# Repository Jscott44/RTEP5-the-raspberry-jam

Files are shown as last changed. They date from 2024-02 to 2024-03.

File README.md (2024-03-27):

<!-- display the social media buttons in your README -->

<!-- To Link your profile to the media buttons -->

# **The Raspberry Jam**

The realtime Raspberry PI powered digital guitar effects pedal.

<div style="float:left;margin:0 1px 1px 0" markdown="2">

logoPicBlkStrip

</div>

# **Usage**

Ensure the Raspberry Pi is updated:

```bash
# Update package lists
sudo apt update

# Upgrade installed packages
sudo apt upgrade

# Remove unused packages
sudo apt autoremove

# Clean up package cache
sudo apt clean
```
Install Git 
```bash
# Install Git
sudo apt-get install git -y

# Verify Git installation
git --version
```
Install ALSA resources
```bash
# Install ALSA utilities and libraries
sudo apt-get install alsa-utils libasound2-dev -y

# Verify ALSA installation
aplay --version
```
Install CMake in order to build the project
```bash
# Install CMake
sudo apt-get install cmake -y

# Verify CMake installation
cmake --version
```
Clone the repository
```bash
# Clone the repository from GitHub
git clone https://github.com/Jscott44/RTEP5-the-raspberry-jam.git

# Change directory to the cloned repository
cd RTEP5-the-raspberry-jam

# List files in the repository
ls
```
For use with a generic sound card a device tree overlay needs to be created.

To make sound card master and Raspberry Pi on I2S bus (credit: https://github.com/AkiyukiOkayasu/RaspberryPi_I2S_Slave):
```bash
# Change to device tree directory
cd deviceTree

# Compile on Raspberry Pi  
dtc -@ -H epapr -O dtb -o genericstereoaudiocodec.dtbo -Wno-unit_address_vs_reg genericstereoaudiocodec.dts

# Copy i2smaster.dtbo to /boot/overlays  
sudo cp genericstereoaudiocodec.dtbo /boot/overlays

# Return to repository directory
cd ..
```

Edit /boot/config.txt   
```/boot/config.txt    # Uncomment some or all of these to enable the optional hardware interface
#dtparam=i2c_arm=on
dtparam=i2s=on
#dtparam=spi=on
dtoverlay=genericstereoaudiocodec
```
To make sound card slave and Raspberry Pi master on I2S bus (credit: https://github.com/AkiyukiOkayasu/RaspberryPi_I2S_Master):

```bash
# Compile on Raspberry Pi
# Change to device tree directory
cd deviceTree

dtc -@ -H epapr -O dtb -o i2smaster.dtbo -Wno-unit_address_vs_reg i2smaster.dts

# Copy i2smaster.dtbo to /boot/overlays  
sudo cp i2smaster.dtbo /boot/overlays

# Return to repository directory
cd ..
```

Edit /boot/config.txt  
```/boot/config.txt
# Uncomment some or all of these to enable the optional hardware interface
#dtparam=i2c_arm=on
dtparam=i2s=on
#dtparam=spi=on
dtoverlay=i2smaster
```

Bulding the project with CMake
```bash 
# Create a build directory (optional)
mkdir -p build
cd build

# Configure the build using CMake
cmake ..

# Build the project
make
```
# **Key Features**
- Realtime audio loop
- Cutsomisable effects
- User profiles
- Low cost
- Simple effect creation
- Specialised audio electronics design
RJ_Schematic_v1 0

# **Social Media Links**
[instagram][2]
[github][5]

[2]: https://www.instagram.com/the_raspberry_jam/ 
[5]: https://github.com/Jscott44/RTEP5-the-raspberry-jam

# **Authors and Roles**
- **Jed Scott**
  - Project Manager, Software (audio driver), Hardware Lead, Social Media Lead
- **Dario Petinella**
  - Software Lead (audio driver, effects manager), Integration Lead, Hardware (audio)
- **Alan Hamilton**
  - Software (GUI Lead and effects integration), Mechanical Support
- **Elad Perets**
  - Software (effects), Hardware (pedal)
- **Matthew Stewart**
  - Software (GUI)

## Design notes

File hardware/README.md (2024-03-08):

# **Hardware**
The Raspberry Jam includes a specialised audio sound card for the capture and playback of high fidelity audio. The impact of the hardware is designed to be as inaudible as possible and all of the effects are achieved digitally in software. The hardware design is modular in nature allowing the cutsomisation to suit different applications.

# **Features**
- Highly integrated stereo audio CODEC
- Sample rates: 44.1kHz, 48kHz, 96kHz or 192kHz
- Hardware or Software control
- On-board oscillator
- 1x mono audio input (guitar)
- 2x stereo outputs (speakers)
- 1x stereo output (headphones with volume control)

# **Audio Inputs and Outputs**
The current version of the sound card supports one single ended mono instrument input up to 2Vrms. 
inputConn

The output support two single ended connectors to create a stereo speaker output with a maximum level of 1.8Vrms before amplification. 
outConn

The output also support a headphone driver with analogue volume to control to adjust to different load impedance headphones.
- Default gain range 18dB.
- To alter gain range adjust R43, R44, R45 and R46.
- Adjust output power by altering R41 and R42.
HPConn

# **CODEC**

cdc

<h2>CS4271 Sample Rate Truth Table</h2>

<table>
  <tr>
    <th>Resistor R49</th>
    <th>Resistor R50</th>
    <th>Resistor R10</th>
    <th>Resistor R11</th>
    <th>M1</th>
    <th>M0</th>
    <th>Sample Rate (kHz)</th>
  </tr>
  <tr>
    <td>Not Populated</td>
    <td>Not Populated</td>
    <td>Populated</td>
    <td>Populated</td>
    <td>0</td>
    <td>0</td>
    <td>44.1</td>
  </tr>
  <tr>
    <td>Not Populated</td>
    <td>Populated</td>
    <td>Populated</td>
    <td>Not Populated</td>
    <td>0</td>
    <td>1</td>
    <td>48</td>
  </tr>
  <tr>
    <td>Populated</td>
    <td>Not Populated</td>
    <td>Not Populated</td>
    <td>Populated</td>
    <td>1</td>
    <td>0</td>
    <td>96</td>
  </tr>
  <tr>
    <td>Populated</td>
    <td>Populated</td>
    <td>Not Populated</td>
    <td>Not Populated</td>
    <td>1</td>
    <td>1</td>
    <td>192</td>
  </tr>
</table>

</body>
</html>
</html>

<h2>CS4271 Audio Mode Truth Table</h2>

<table>
  <tr>
    <th>R9 </th>
    <th>R32 </th>
    <th>ADO </th>
    <th>Audio Mode</th>
  </tr>
  <tr>
    <td>Populated</td>
    <td>Not Populated</td>
    <td>1</td>
    <td>I2S</td>
  </tr>
  <tr>
    <td>Not Populated</td>
    <td>Populated</td>
    <td>0</td>
    <td>Left Justified</td>
  </tr>

  </tr>
</table>

</body>
</html>

# **Digital Audio Format**

By default the digital audio interface will operate using the I2S protocol
- MSB first (big endian)
- Signed 24-bits per channel
- 2 channels
- Interleaved channels

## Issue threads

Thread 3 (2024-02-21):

Driver for capture from generic PCM device

Jscott44, 2024-02-21:
Basic functionality to recognise and then read from PCM device

iamdario, 2024-02-22:
Created _audio_driver_dev_ branch for development to begin.

Jscott44, 2024-02-26:
Created branch for specific capture development

Jscott44, 2024-03-04:
Created basic framework for a generic device, waiting for finalised development of hardware platform in order to properly test interface with RPI.

iamdario, 2024-03-14:
Has been implemented in the branch 'capture-from-generic-pcm-device'. Need to now merge effects manager to begin testing.

iamdario, 2024-03-23:
Has been achieved and merged back into 'audio_driver_dev' branch in pull request #58 .

Closed 2024-03-23.

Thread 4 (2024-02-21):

Driver for playback to generic PCM device

Jscott44, 2024-02-21:
Functionality to write to a PCM device

iamdario, 2024-02-22:
Created _audio_driver_dev_ branch for development to begin.

Jscott44, 2024-03-04:
Waiting for hardware platform to be finished.

Jscott44, 2024-03-05:
Added parent class that will define basic functions and configure settings. Capture and playback will be children of this class, settings are shared as much as possible and functions will be implemented differently where necessary.

iamdario, 2024-03-14:
Has been implemented in the branch 'capture-from-generic-pcm-device'. Need to now merge effects manager to begin testing.

iamdario, 2024-03-23:
Has been achieved and merged back into 'audio_driver_dev' branch in pull request #58 .

Closed 2024-03-23.

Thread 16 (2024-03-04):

QTabWidget Current Index -> Effects Manager pointer relation

AlanHam42, 2024-03-04:
The user can only affect the current index of tabs.
The EM returns a pointer for each new tab.
Each pointer needs to be stored in the same order as the tabs, and destroyed with the tabs.
The current index can then refer to the correct pointer, which will return values to the EM.

theOriginalMC, 2024-03-29:
GUI now receives a pointer and sends variables to the Effects Manager

Closed 2024-03-29.

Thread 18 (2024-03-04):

Create Basic Effects Manager

iamdario, 2024-03-04:
This class will be responsible for taking the data from Alsa (that has been converted using AlsaBufferConverter into a usable form) and applying effects to the data. Some of the groundwork must also be created to allow the GUI to create/destroy different effects.

iamdario, 2024-03-05:
Basic functionality has been added. Can now add effects, remove effects and apply effects to data.

iamdario, 2024-03-05:
Next: Add way to allow GUI to alter parameters effect classes by calling method

iamdario, 2024-03-14:
As basic functionality has been achieved, it will now be merged with the pcm driver classes to begin testing. Any further alterations required will be added as their own issues.

Closed 2024-03-14.

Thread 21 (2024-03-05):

Add setup and usage instructions for Raspberry Jam in README

Jscott44, 2024-03-05:
Once hardware is finalised this can be done.

Jscott44, 2024-03-05:
This also applies to generally fleshing out the documentation for the project.

Jscott44, 2024-03-12:
Added basic update commands for rpi and git install instructions

Jscott44, 2024-03-22:
This now includes all needed steps to set up RPI for use with program including creating a device tree overlay if required.

Jscott44, 2024-03-22:
Done

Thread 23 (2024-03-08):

Convert #20 Wrapper Class to use Proper Callbacks

iamdario, 2024-03-08:
Wrapper class should not be used. Create a branch which experiments with having all the classes reference each other to allow for thread-safe callbacks.

iamdario, 2024-03-08:
Branched from issue #20 to experiment with using callbacks instead of wrapper

iamdario, 2024-03-11:
Has been merged into #18 in pull request #24 and #25.

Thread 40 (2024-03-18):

Alter AlsaBufferConverter and EffectsManager to Avoid Buffer Reallocation

iamdario, 2024-03-18:
Currently, whenever we receive a sample from Alsa, two new ChannelSample objects are created. These are allocating memory which is inefficient. What if, instead, we have these object allocate memory in their constructor and remove them from the loop. The buffers are then reallocated every time data is received via the callback.

iamdario, 2024-03-19:
ChannelSamples has been changed to use fixed arrays allocated on the heap rather than vectors. This will allow the same buffers to be reused instead of constantly deleting and creating ChannelSample objects on the heap which would each be responsible for their own vectors. Now, two ChannelSample objects are created on the heap in the constructor of EffectsManager. These objects are constnatly reused until the EffectsManager object is destroyed.

Closed 2024-03-19.

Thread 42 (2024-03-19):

Pthread_mutex_unlock error when running on RPI

Jscott44, 2024-03-19:
Program terminates when run on RPI stating an error with the unlocking a mutex, this does not occur on PC running Linux. Will experiment with compatibility of capture hardware.

Jscott44, 2024-03-19:
Might be caused by sample rate mismatch - will verify.

Closed 2024-03-21.

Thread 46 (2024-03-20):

PcmCapture Unable to Drain

iamdario, 2024-03-20:
It was noticed that the drain handle call for PcmCapture is unable to execute, with the call blocking the program from continuing to function. This only occurs if data has been read. If drain handle is called without ever reading anything, the drain is able to successfully execute.

iamdario, 2024-03-21:
We have noticed that increasing the number of frames per buffer has resolved this issue. We are now using 9600 instead of 128 as we were using before.

iamdario, 2024-03-21:
Issue has been resolved. See Issue #54

Closed 2024-03-21.

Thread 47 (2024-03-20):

Adjust Device Name

iamdario, 2024-03-20:
We have learned that we will likely need to be able to change the device name of the PCM handle. We will need to adjust the code accordingly.

iamdario, 2024-03-21:
Has been resolved. Users can now customise device names from main.cpp. Merged done in #48.

Closed 2024-03-21.

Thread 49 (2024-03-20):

Create Folder Containing Sample Code to Test Hardware

iamdario, 2024-03-20:
Currently, we are struggling to see whether issues arising are from hardware or software. For this reason, we will make a new folder which just has some sample scripts allowing hardware to be tested without the need of running our program. This will allow us to narrow down issues more quickly.

iamdario, 2024-03-21:
Resolved in Pull Request #55 . See Issue #54 .

Closed 2024-03-21.

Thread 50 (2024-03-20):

Adjust Values in Code to use New ADC

iamdario, 2024-03-20:
From experimenting using test programs, we have found that our new ADC has different parameters than what we were expecting. Therefore we will need to adjust these parameters within the code. We have noticed the following:

- The ADC needs 96000Hz sampling rate
- The ADC need uses INT16s instead of INT24s. When adjusting this, we will want to ensure we can easily swap between 16 bit and 24 bit to be compatible with as much audio
- Potentially increase the number of frames as we have noticed that this improved performance (reduced the number of times the ALSA read/write commands failed)

iamdario, 2024-03-20:
Adjusted to allow code to use both int16s and int24. Need to figure out a way to more easily swap between the two. However, the code also needs to be able to handle little endian int16s which it is currently unable to do. Currently considering using an enum and switch statement.

iamdario, 2024-03-21:
The issue has now been solved and we can run the program with the new ADC we have. To do this, we have:
- Allowed the bytes per sample to be swapped between 2 and 3. If it is 2, AlsaBufferConverter will recognise that the ADC will get INT16s and the same will happen when it is 3, with the program recognising that it is using INT24s.
- Program now uses a sample rate of 96kHz and a buffer size of 128. This is a rather large buffer and will potentially result in a noticeable delay. Further investigation is required.
- Program can now swap between reading/writing data as little endian and big endian. This must be adjusted in the header file of AlsaBufferConverter.

These changes have also highlighted another issue. We are realising that, to make this program as flexible as possible, we want to be able to change these values from multiple locations at once to allow users to be able to change these values easily. This will be further investigated in a separate issue.

iamdario, 2024-03-21:
Issue #51 has addressed the previous comment by allowing users to adjust various parameters within main.cpp. Please refer to that issue for further information.

iamdario, 2024-03-21:
Issues is resolved. Merged back into #38.

Closed 2024-03-21.

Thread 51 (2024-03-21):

Allow User to Easily Adjust Values within main.cpp

iamdario, 2024-03-21:
In Issue #50, we have noticed that we will likely have to change values within the code. Right now, it is a painful process as values must be the same within multiple files. I want to change this to allow the user to declare all of these values in the main.cpp file and the constructors of all the classes will take these values as arguments and adjust their code accordingly. The values we want to be able to adjust are:
- Sample Type (INT16 or INT24)
- Sample frequency (96kHz or 44.1kHz)
- Endianness (Little or Big)
- Frames per buffer

iamdario, 2024-03-21:
Has now been resolved. User can now adjust the sample rate, frames per buffer and data format in main.cpp. The program can then figure out what it needs to do from there.

Closed 2024-03-21.

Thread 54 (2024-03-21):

Merge Fixed ALSA Issues

iamdario, 2024-03-21:
From developing the program to use the new ADC discussed in Issue #50 and #51, we have resolved various issues in the process. These include:
- Issue #49 (we no longer need these test files as they were there to figure out the desired digital format for the ADC we were using)
- Issue #46 (it can drain now that we have increased the frames per buffer received.
- Issue #42 (this only occurred once. Upon rebooting the RPI, it disappeared)

These, however, still have branches associated with this. We must clean these branches up.

iamdario, 2024-03-21:
Realised I did not have make this branch. Instead, I can just close all of these open branches that have been resolved separately.

iamdario, 2024-03-21:
Deleting this branch now.

Closed 2024-03-21.

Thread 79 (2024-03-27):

Fix reverb segmentation fault bug

e-perets, 2024-03-27:
Fir filter is causing the program to not run in real time and causing a segmentation fault.

Closed 2024-03-27.

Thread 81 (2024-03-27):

Fix reverb delay line in attempts to make it run in real time

e-perets, 2024-03-27:
The FIR filter method causes segmentation faults and does not run in real time. Attempt implement a ring buffer without the fir library.

Jscott44, 2024-03-28:
tested on rpi, works well

Closed 2024-03-28.

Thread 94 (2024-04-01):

Button for enabling/disabling effect proccessing

iamdario, 2024-04-01:
A button will be required to enable/disable the effects from processing the incoming buffers. This button will interact with the rest of the code using a callback from a class responsible for waiting for an interrupt from a GPIO pin.

Jscott44, 2024-04-04:
Moving to a hybrid system that can use a hardware button or a purely digital button.

AlanHam42, 2024-04-12:
Button has been implemented in GUI.

Closed 2024-04-12.

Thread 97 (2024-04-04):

PiGPIO Conflicts with PCM devices

Jscott44, 2024-04-04:
By default PiGPIO uses the PCM clock (and thus the pins) to establish timing. Most audio devices use the PCM pins also. One can configure PiGPIO to use the PWM clock instead, however it appears the internal sound card on the RPI also uses the PWM clock. Thus, PiGPIO can only be used with using a full duplex sound card on PCM pins and configuring PiGPIO to use the PWM clock.

iamdario, 2024-04-05:
After further testing, we have discovered that the physical button component of The Raspberry Jam would likely not work even with a full duplex sound card. This is because, in order for the button to work, the library being used to read the GPIO pins (PiGPIO) would require SU privileges. However, it has been found that ALSA is unable to function when given SU privileges. This hypothesis was confirmed by the following forum: [Link](https://www.linuxquestions.org/questions/showthread.php?p=6417492#post6417492).

Until a work around is found, this project will move towards implementing a digital button using the GUI.

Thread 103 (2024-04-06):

GUI Only Button

AlanHam42, 2024-04-06:
Ditching the hardware button for now due to issues with Sudo, moving to a digital only button.

Closed 2024-04-12.

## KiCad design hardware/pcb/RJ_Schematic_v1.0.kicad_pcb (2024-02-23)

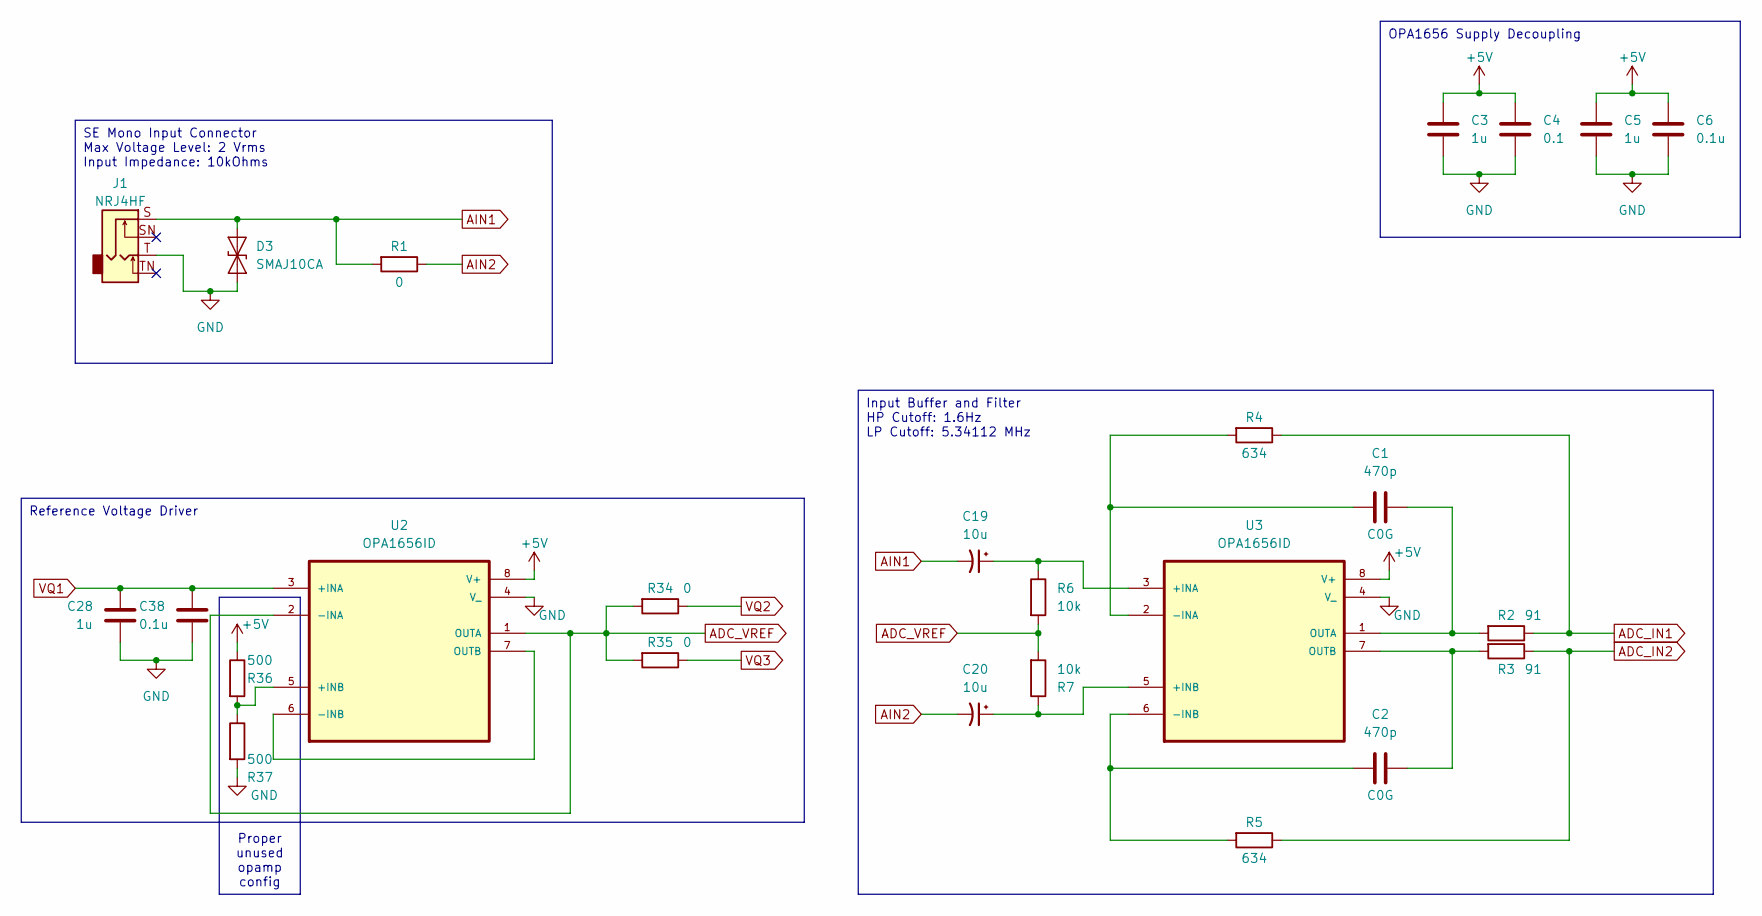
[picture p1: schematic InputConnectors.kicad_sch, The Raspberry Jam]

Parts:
C1, C2: 470p; C_0805_2012Metric_Pad1.18x1.45mm_HandSolder
C3, C5, C28: 1u; C_0805_2012Metric_Pad1.18x1.45mm_HandSolder
C4: 0.1; C_0805_2012Metric_Pad1.18x1.45mm_HandSolder
C6, C38: 0.1u; C_0805_2012Metric_Pad1.18x1.45mm_HandSolder
C19, C20: 10u; CP_Elec_4x5.4
D3: SMAJ10CA; D_SMA
J1: NRJ4HF; Jack_6.35mm_Neutrik_NRJ4HF_Horizontal
R1, R34, R35: 0; R_0805_2012Metric_Pad1.20x1.40mm_HandSolder
R2, R3: 91; R_0805_2012Metric_Pad1.20x1.40mm_HandSolder
R4, R5: 634; R_0805_2012Metric_Pad1.20x1.40mm_HandSolder
R6, R7: 10k; R_0805_2012Metric_Pad1.20x1.40mm_HandSolder
R36, R37: 500; R_0805_2012Metric_Pad1.20x1.40mm_HandSolder
U2, U3: OPA1656ID; SOIC127P599X175-8N

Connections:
+5V: C3.2, C4.2, C5.2, C6.2, R36.1, U2.8 (V+), U3.8 (V+); also elsewhere on the board
ADC_IN1: R2.1, R4.1; also elsewhere on the board
ADC_IN2: R3.1, R5.1; also elsewhere on the board
ADC_VREF: R6.2, R7.2, R34.2, R35.2, U2.1 (OUTA), U2.2 (-INA)
AIN1: C19.2, D3.2 (A2), J1.S, R1.2
AIN2: C20.2, R1.1
GND: C3.1, C4.1, C5.1, C6.1, C28.1, C38.1, D3.1 (A1), J1.T, R37.2, U2.4 (V_), U3.4 (V_); also elsewhere on the board
unnamed: R36.2, R37.1, U2.5 (+INB)
unnamed: U2.6 (-INB), U2.7 (OUTB)
unnamed: C19.1, R6.1, U3.3 (+INA)
unnamed: C20.1, R7.1, U3.5 (+INB)
unnamed: C1.2, R4.2, U3.2 (-INA)
unnamed: C2.2, R5.2, U3.6 (-INB)
unnamed: C1.1, R2.2, U3.1 (OUTA)
unnamed: C2.1, R3.2, U3.7 (OUTB)
VQ1: C28.2, C38.2, U2.3 (+INA); also elsewhere on the board
VQ2: R34.1; also elsewhere on the board
VQ3: R35.1; also elsewhere on the board

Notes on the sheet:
Proper unused opamp config
Input Buffer and Filter HP Cutoff: 1.6Hz LP Cutoff: 5.34112 MHz
OPA1656 Supply Decoupling
Reference Voltage Driver
SE Mono Input Connector Max Voltage Level: 2 Vrms Input Impedance: 10kOhms

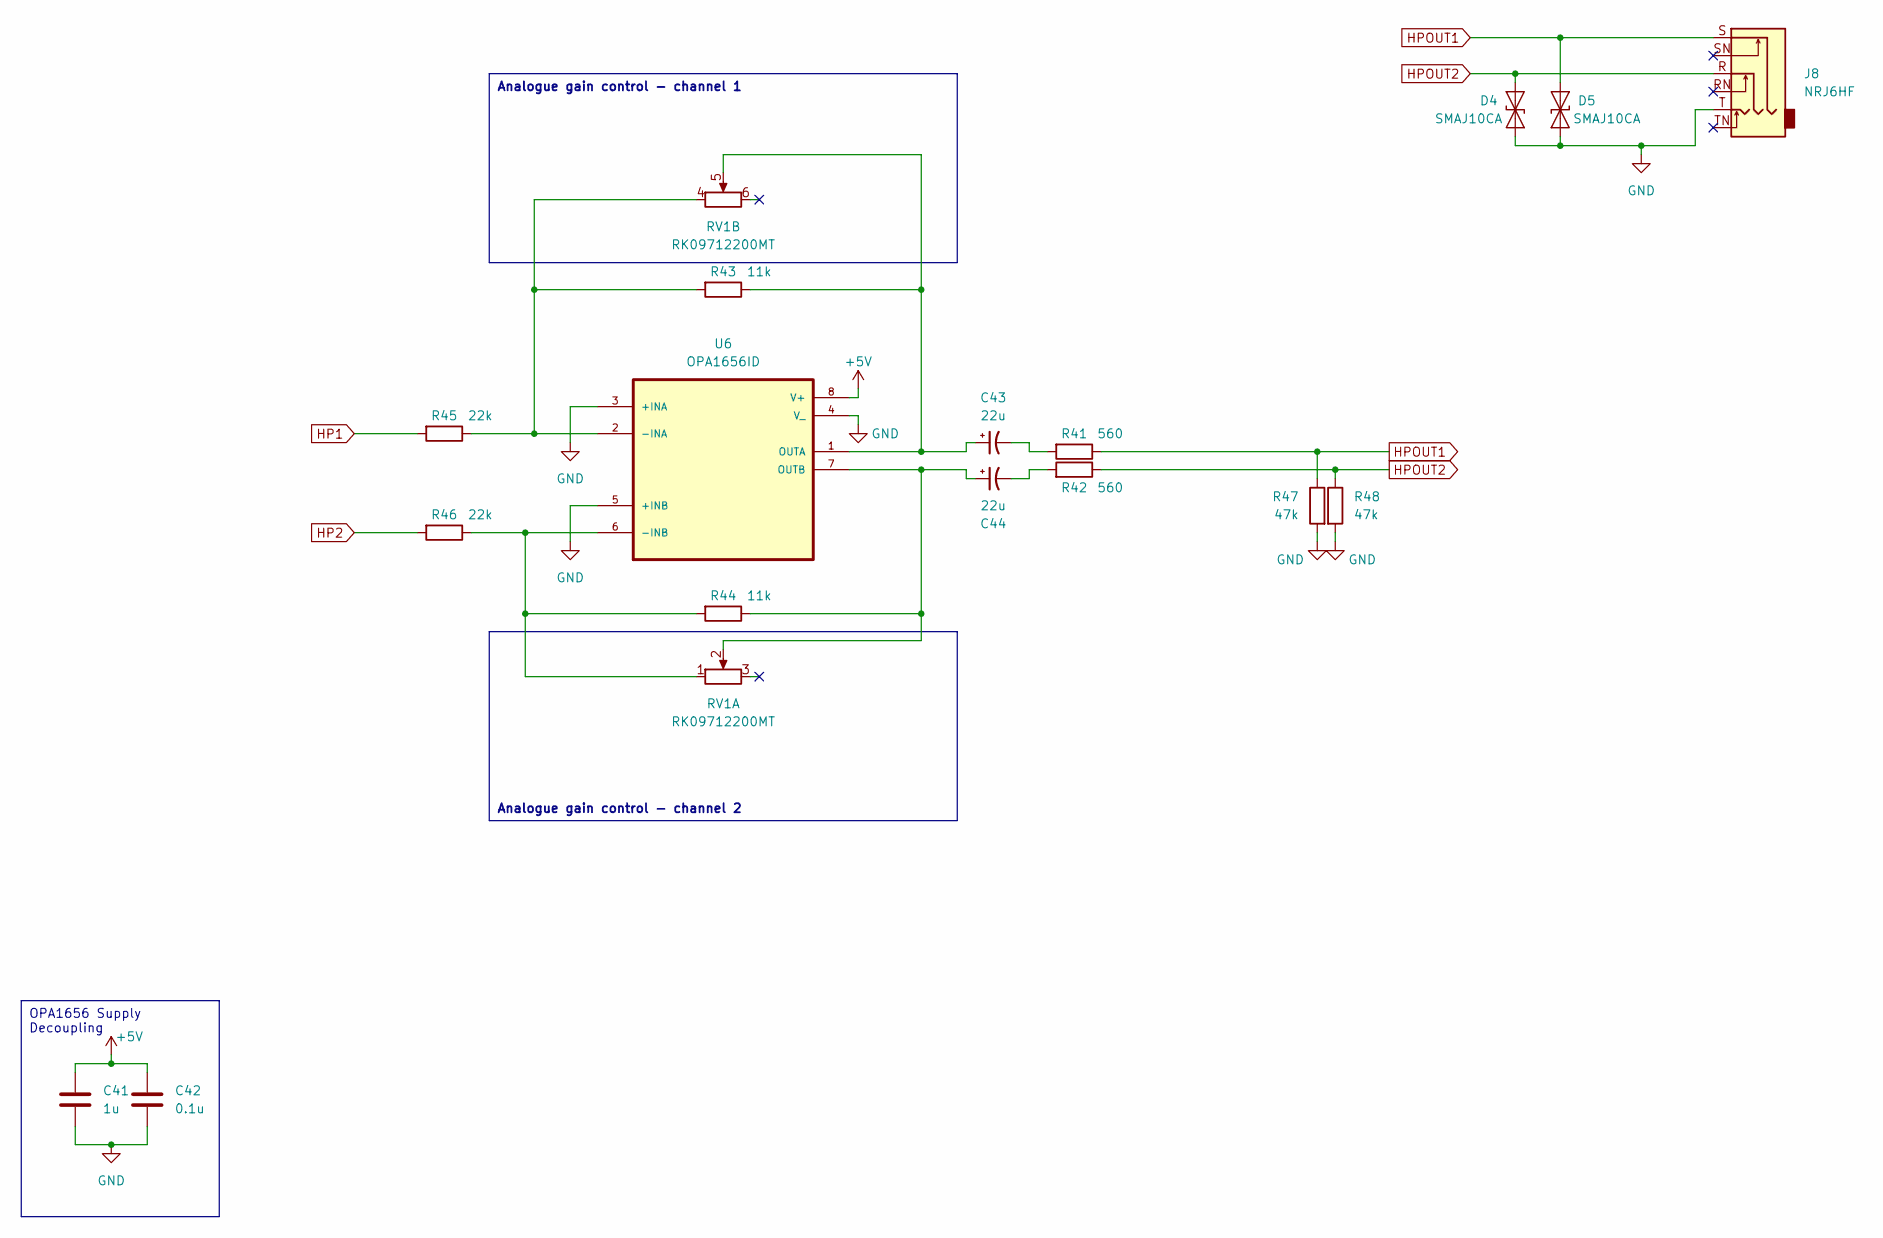
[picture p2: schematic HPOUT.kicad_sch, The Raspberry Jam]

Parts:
C41: 1u; C_0805_2012Metric_Pad1.18x1.45mm_HandSolder
C42: 0.1u; C_0805_2012Metric_Pad1.18x1.45mm_HandSolder
C43, C44: 22u; CP_Elec_5x5.7
D4, D5: SMAJ10CA; D_SMA
J8: NRJ6HF; Jack_6.35mm_Neutrik_NRJ6HF_Horizontal
R41, R42: 560; R_0805_2012Metric_Pad1.20x1.40mm_HandSolder
R43, R44: 11k; R_0805_2012Metric_Pad1.20x1.40mm_HandSolder
R45, R46: 22k; R_0805_2012Metric_Pad1.20x1.40mm_HandSolder
R47, R48: 47k; R_0805_2012Metric_Pad1.20x1.40mm_HandSolder
RV1: RK09712200MT; Potentiometer_Alps_RK097_Dual_Horizontal
U6: OPA1656ID; SOIC127P599X175-8N

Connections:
+5V: C41.2, C42.2, U6.8 (V+); also elsewhere on the board
GND: C41.1, C42.1, D4.1 (A1), D5.1 (A1), J8.T, R47.2, R48.2, U6.3 (+INA), U6.4 (V_), U6.5 (+INB); also elsewhere on the board
HP1: R45.2; also elsewhere on the board
HP2: R46.2; also elsewhere on the board
HPOUT1: D5.2 (A2), J8.S, R41.1, R47.1
HPOUT2: D4.2 (A2), J8.R, R42.1, R48.1
unnamed: C43.2, R41.2
unnamed: C44.2, R42.2
unnamed: R43.2, R45.1, RV1.4, U6.2 (-INA)
unnamed: R44.2, R46.1, RV1.1, U6.6 (-INB)
unnamed: C43.1, R43.1, RV1.5, U6.1 (OUTA)
unnamed: C44.1, R44.1, RV1.2, U6.7 (OUTB)

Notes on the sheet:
OPA1656 Supply Decoupling
Analogue gain control - channel 2
Analogue gain control - channel 1

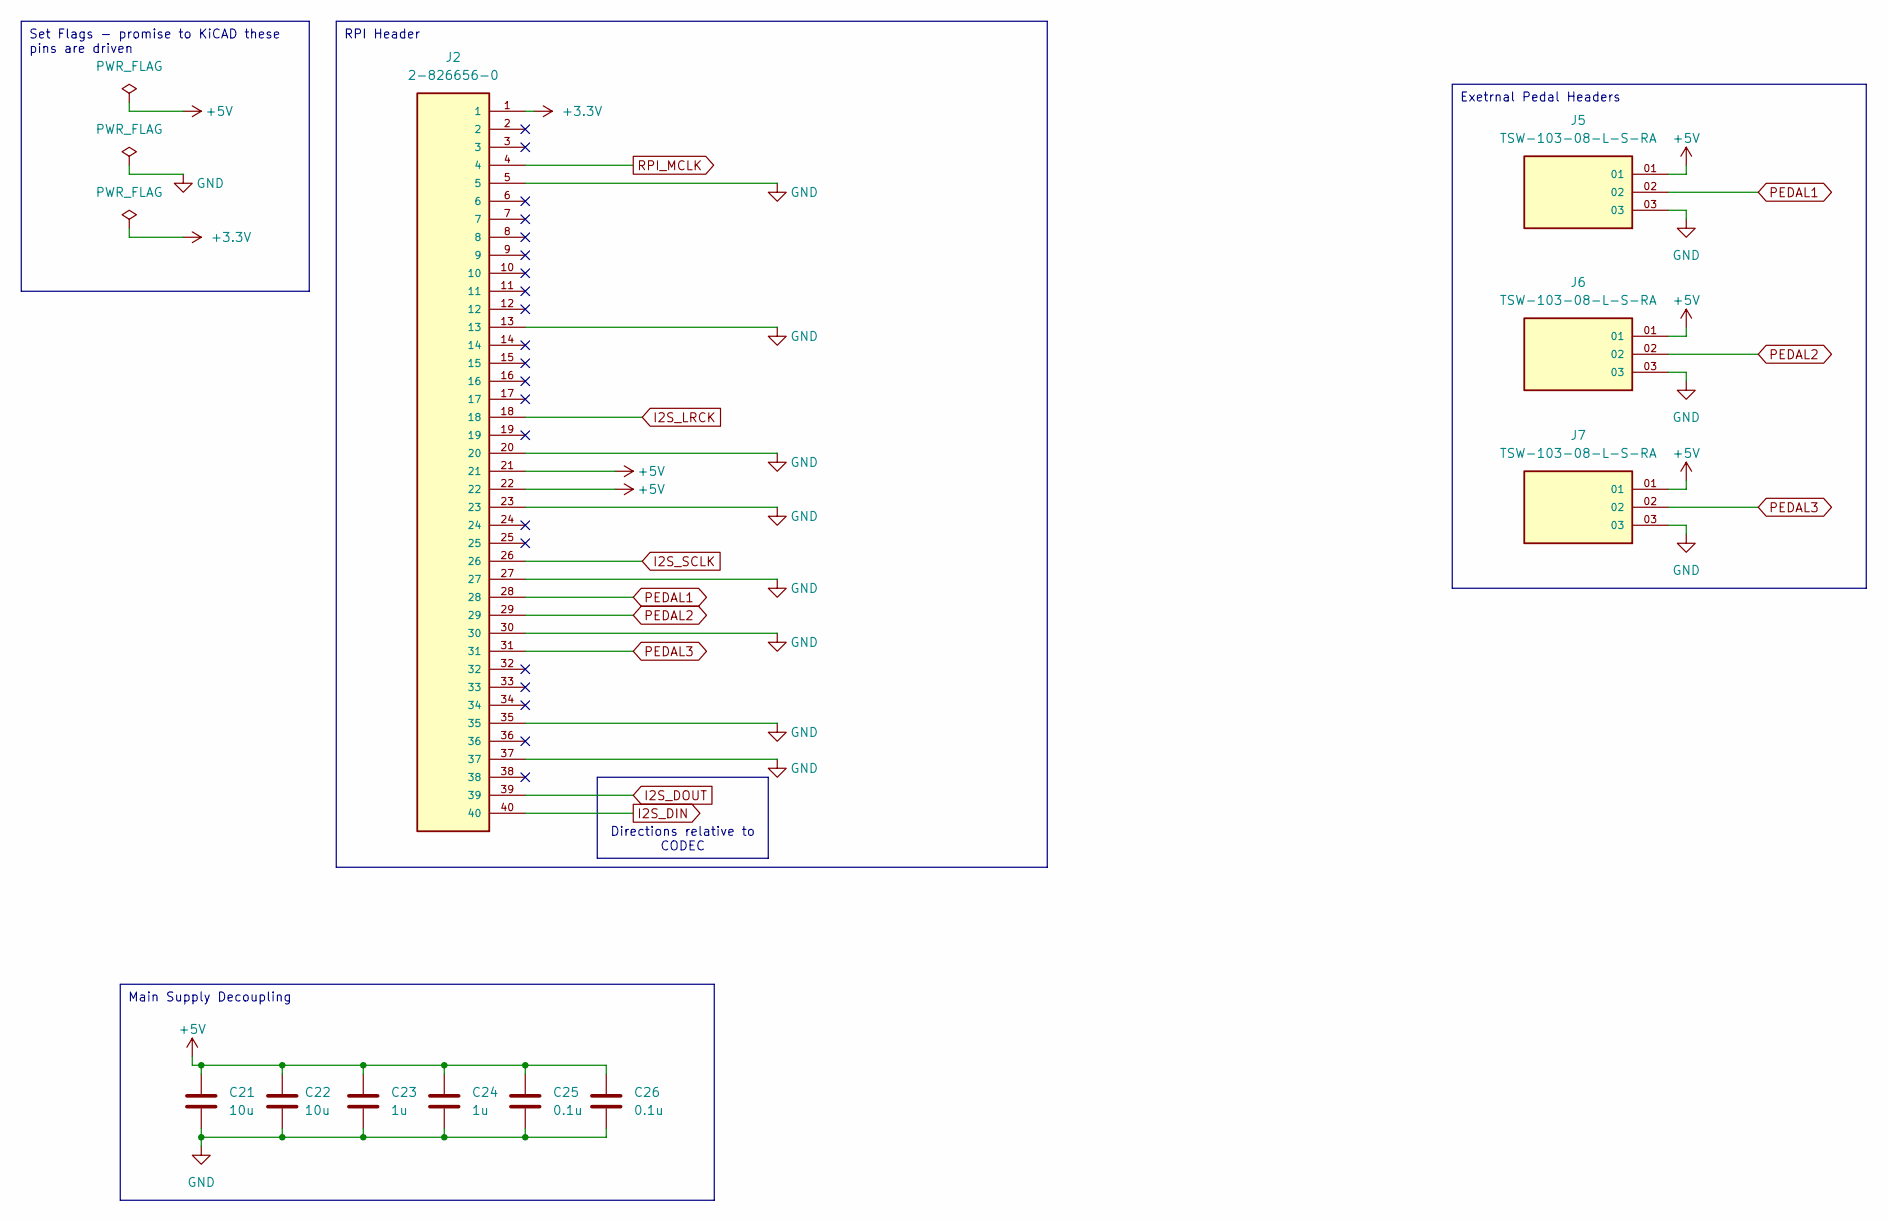
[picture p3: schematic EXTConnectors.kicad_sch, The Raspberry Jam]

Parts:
C21, C22: 10u; C_0805_2012Metric_Pad1.18x1.45mm_HandSolder
C23, C24: 1u; C_0805_2012Metric_Pad1.18x1.45mm_HandSolder
C25, C26: 0.1u; C_0805_2012Metric_Pad1.18x1.45mm_HandSolder
J2: 2-826656-0; TE_2-826656-0; PARTREV R
J5, J6, J7: TSW-103-08-L-S-RA; SAMTEC_TSW-103-08-L-S-RA; PARTREV R

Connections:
+3.3V: J2.1; also elsewhere on the board
+5V: C21.1, C22.1, C23.1, C24.1, C25.1, C26.1, J2.21, J2.22, J5.01, J6.01, J7.01; also elsewhere on the board
GND: C21.2, C22.2, C23.2, C24.2, C25.2, C26.2, J2.5, J2.13, J2.20, J2.23, J2.27, J2.30, J2.35, J2.37, J5.03, J6.03, J7.03; also elsewhere on the board
I2S_DIN: J2.40; also elsewhere on the board
I2S_DOUT: J2.39; also elsewhere on the board
I2S_LRCK: J2.18; also elsewhere on the board
I2S_SCLK: J2.26; also elsewhere on the board
PEDAL1: J2.28, J5.02
PEDAL2: J2.29, J6.02
PEDAL3: J2.31, J7.02
RPI_MCLK: J2.4; also elsewhere on the board

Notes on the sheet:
Exetrnal Pedal Headers
RPI Header
Directions relative to CODEC
Main Supply Decoupling
Set Flags - promise to KiCAD these pins are driven

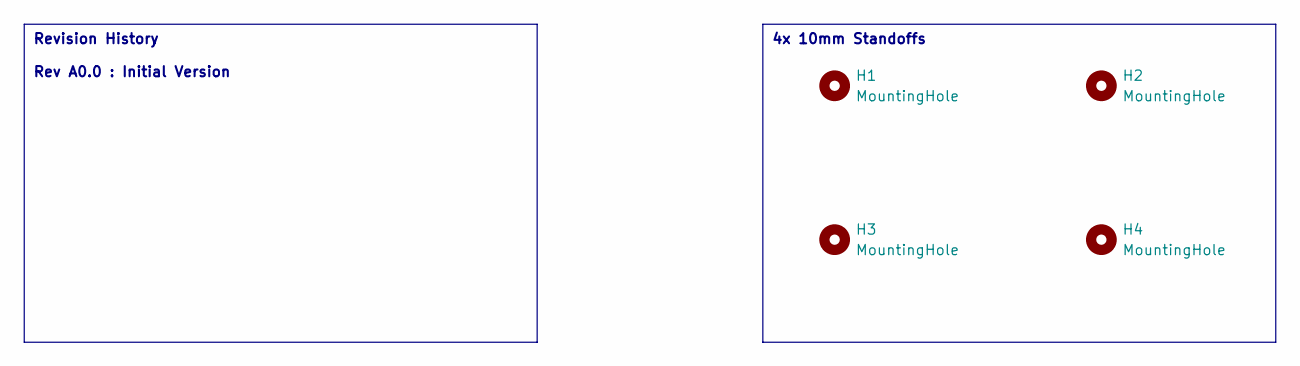
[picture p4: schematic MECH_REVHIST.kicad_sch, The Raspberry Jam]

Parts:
H1, H2, H3, H4: MountingHole; MountingHole_2.2mm_M2

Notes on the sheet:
Revision History Rev A0.0 : Initial Version
4x 10mm Standoffs

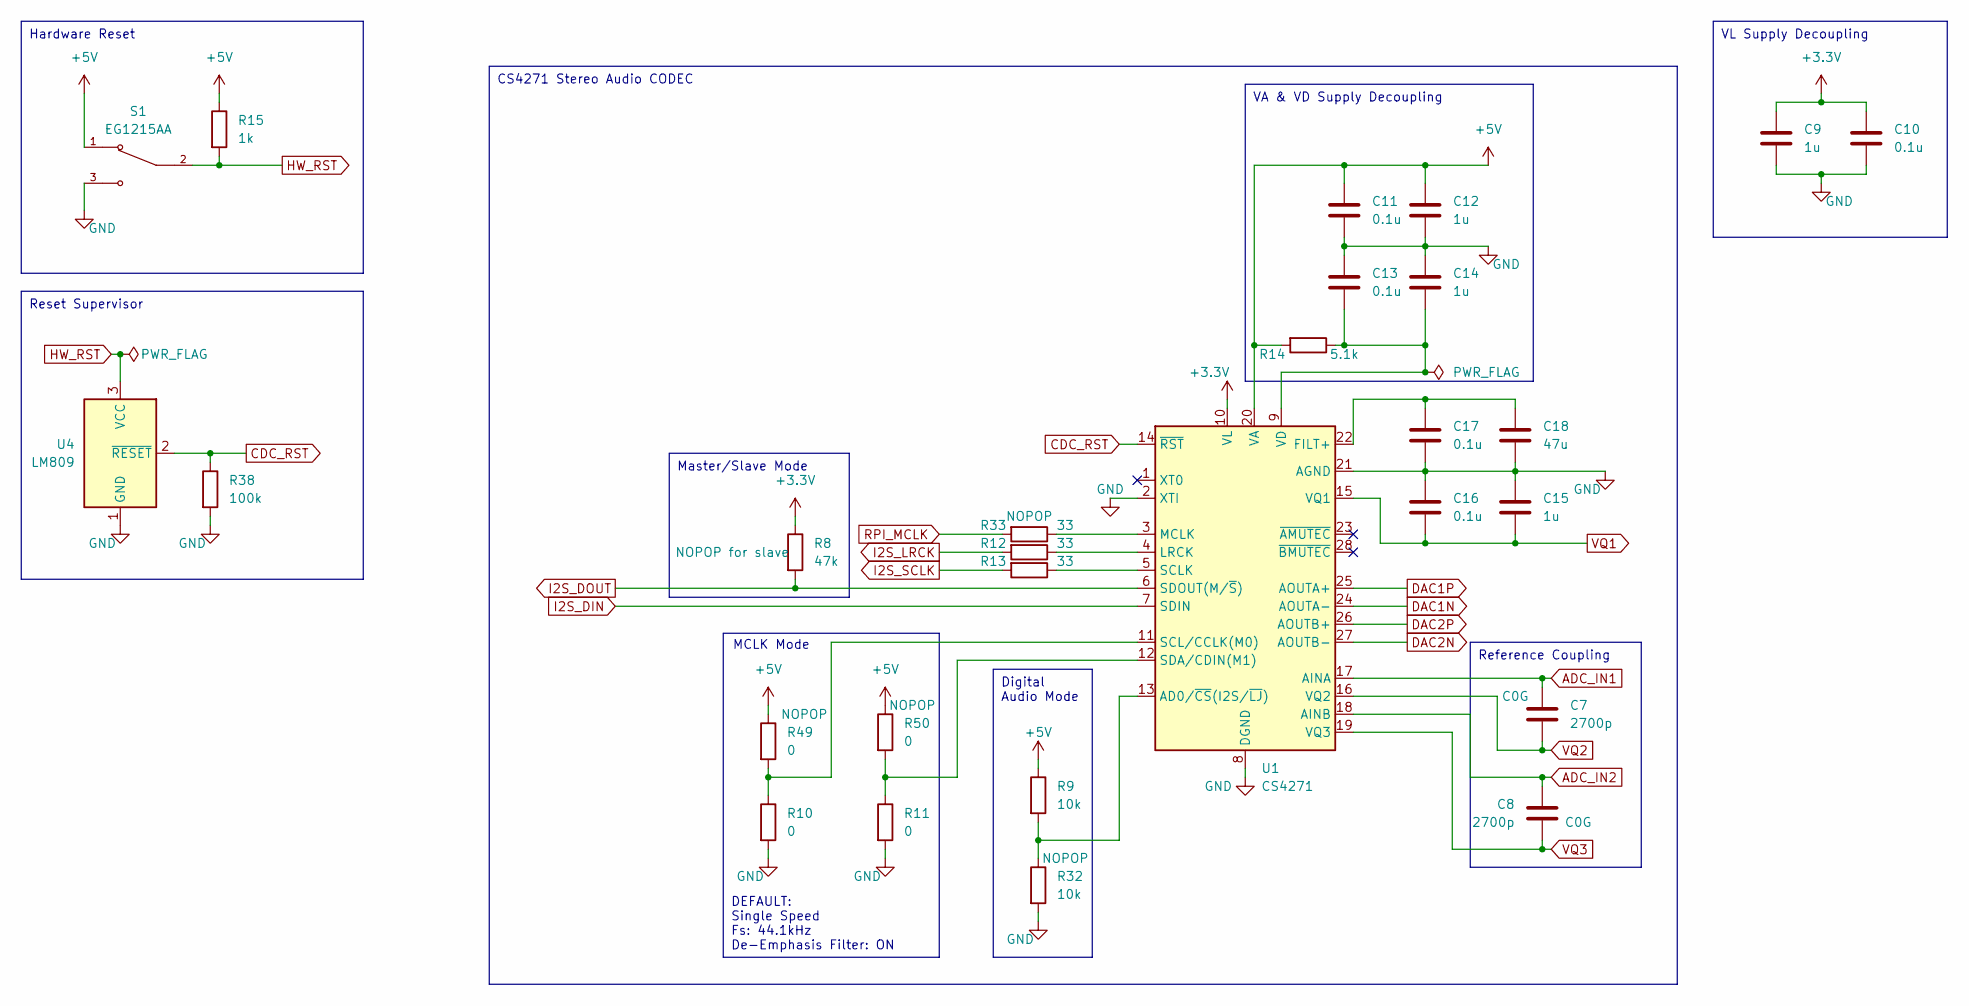
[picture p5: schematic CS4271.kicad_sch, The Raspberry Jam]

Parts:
C7, C8: 2700p; C_0805_2012Metric_Pad1.18x1.45mm_HandSolder
C9, C12, C14, C15: 1u; C_0805_2012Metric_Pad1.18x1.45mm_HandSolder
C10, C11, C13, C16, C17: 0.1u; C_0805_2012Metric_Pad1.18x1.45mm_HandSolder
C18: 47u; C_0805_2012Metric_Pad1.18x1.45mm_HandSolder
R8: 47k; R_0805_2012Metric_Pad1.20x1.40mm_HandSolder
R9, R32: 10k; R_0805_2012Metric_Pad1.20x1.40mm_HandSolder
R10, R11, R49, R50: 0; R_0805_2012Metric_Pad1.20x1.40mm_HandSolder
R12, R13, R33: 33; R_0805_2012Metric_Pad1.20x1.40mm_HandSolder
R14: 5.1k; R_0805_2012Metric_Pad1.20x1.40mm_HandSolder
R15: 1k; R_0805_2012Metric_Pad1.20x1.40mm_HandSolder
R38: 100k; R_0805_2012Metric_Pad1.20x1.40mm_HandSolder
S1: EG1215AA; SW_EG1215AA; PARTREV A
U1: CS4271; TSSOP-28_4.4x9.7mm_P0.65mm
U4: LM809; SOT-23

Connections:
+3.3V: C9.1, C10.1, R8.1, U1.10 (VL); also elsewhere on the board
+5V: C11.1, C12.1, R9.1, R14.2, R15.1, R49.1, R50.1, S1.1, U1.20 (VA); also elsewhere on the board
ADC_IN1: C7.1, U1.17 (AINA); also elsewhere on the board
ADC_IN2: C8.2, U1.18 (AINB); also elsewhere on the board
CDC_RST: R38.1, U1.14 (~RST), U4.2 (~RESET)
DAC1N: U1.24 (AOUTA-); also elsewhere on the board
DAC1P: U1.25 (AOUTA+); also elsewhere on the board
DAC2N: U1.27 (AOUTB-); also elsewhere on the board
DAC2P: U1.26 (AOUTB+); also elsewhere on the board
GND: C9.2, C10.2, C11.2, C12.2, C13.1, C14.1, C15.1, C16.1, C17.2, C18.2, R10.2, R11.2, R32.2, R38.2, S1.3, U1.2 (XTI), U1.8 (DGND), U1.21 (AGND), U4.1 (GND); also elsewhere on the board
HW_RST: R15.2, S1.2, U4.3 (VCC)
I2S_DIN: U1.7 (SDIN); also elsewhere on the board
I2S_DOUT: R8.2, U1.6 (SDOUT(M/~S)); also elsewhere on the board
I2S_LRCK: R12.2; also elsewhere on the board
I2S_SCLK: R13.2; also elsewhere on the board
unnamed: R9.2, R32.1, U1.13 (AD0/~CS(I2S/~LJ))
unnamed: C17.1, C18.1, U1.22 (FILT+)
unnamed: R12.1, U1.4 (LRCK)
unnamed: R33.1, U1.3 (MCLK)
unnamed: R13.1, U1.5 (SCLK)
unnamed: R10.1, R49.2, U1.11 (SCL/CCLK(M0))
unnamed: R11.1, R50.2, U1.12 (SDA/CDIN(M1))
unnamed: C13.2, C14.2, R14.1, U1.9 (VD)
RPI_MCLK: R33.2; also elsewhere on the board
VQ1: C15.2, C16.2, U1.15 (VQ1); also elsewhere on the board
VQ2: C7.2, U1.16 (VQ2); also elsewhere on the board
VQ3: C8.1, U1.19 (VQ3); also elsewhere on the board

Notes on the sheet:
DEFAULT: Single Speed Fs: 44.1kHz De-Emphasis Filter: ON
Hardware Reset
Digital Audio Mode
Reset Supervisor
Reference Coupling
Master/Slave Mode
CS4271 Stereo Audio CODEC
VL Supply Decoupling
VA & VD Supply Decoupling
MCLK Mode

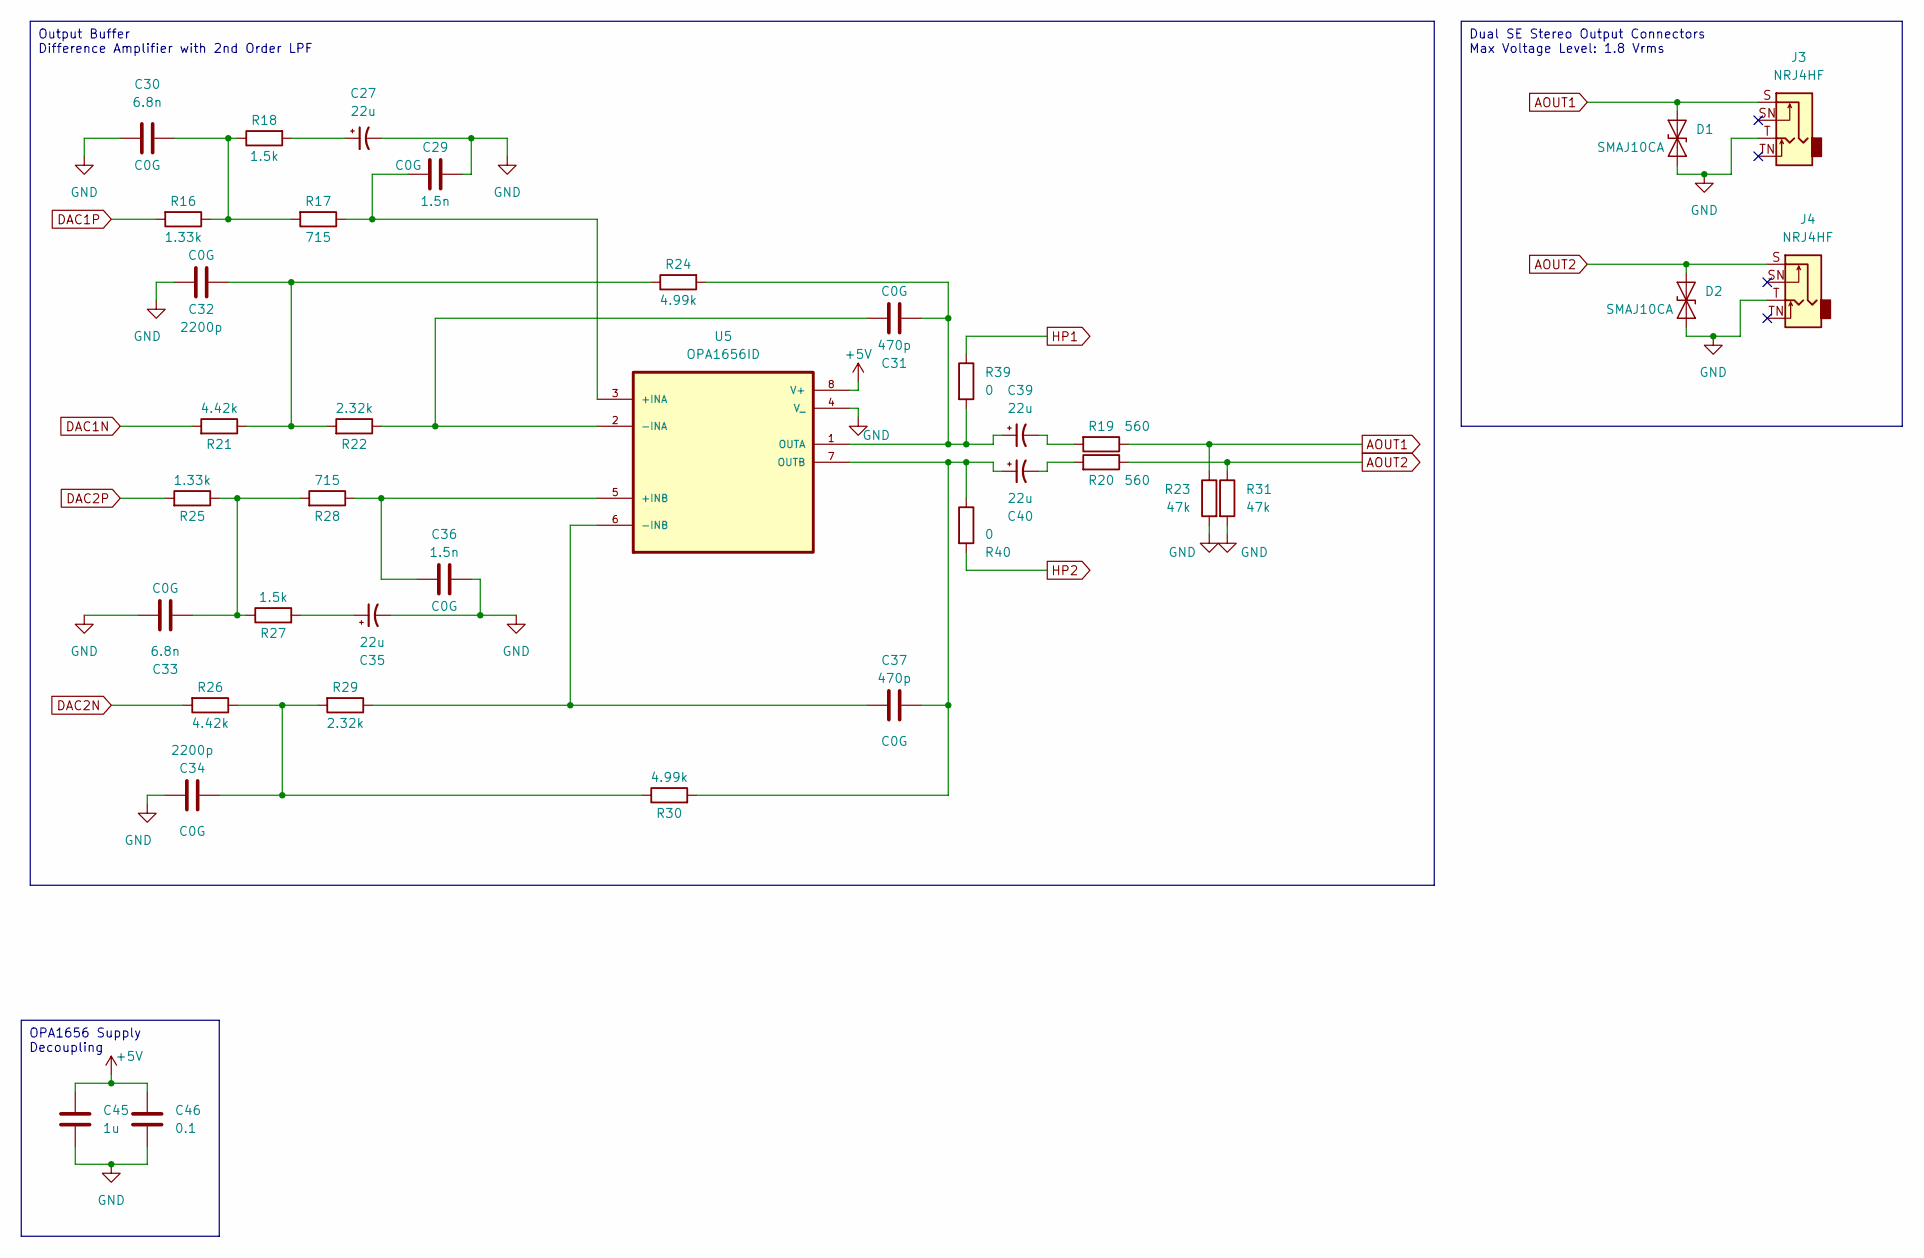
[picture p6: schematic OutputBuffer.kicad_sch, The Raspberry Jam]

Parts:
C27, C35, C39, C40: 22u; CP_Elec_5x5.7
C29, C36: 1.5n; C_0805_2012Metric_Pad1.18x1.45mm_HandSolder
C30, C33: 6.8n; C_0805_2012Metric_Pad1.18x1.45mm_HandSolder
C31, C37: 470p; C_0805_2012Metric_Pad1.18x1.45mm_HandSolder
C32, C34: 2200p; C_0805_2012Metric_Pad1.18x1.45mm_HandSolder
C45: 1u; C_0805_2012Metric_Pad1.18x1.45mm_HandSolder
C46: 0.1; C_0805_2012Metric_Pad1.18x1.45mm_HandSolder
D1, D2: SMAJ10CA; D_SMA
J3, J4: NRJ4HF; Jack_6.35mm_Neutrik_NRJ4HF_Horizontal
R16, R25: 1.33k; R_0805_2012Metric_Pad1.20x1.40mm_HandSolder
R17, R28: 715; R_0805_2012Metric_Pad1.20x1.40mm_HandSolder
R18, R27: 1.5k; R_0805_2012Metric_Pad1.20x1.40mm_HandSolder
R19, R20: 560; R_0805_2012Metric_Pad1.20x1.40mm_HandSolder
R21, R26: 4.42k; R_0805_2012Metric_Pad1.20x1.40mm_HandSolder
R22, R29: 2.32k; R_0805_2012Metric_Pad1.20x1.40mm_HandSolder
R23, R31: 47k; R_0805_2012Metric_Pad1.20x1.40mm_HandSolder
R24, R30: 4.99k; R_0805_2012Metric_Pad1.20x1.40mm_HandSolder
R39, R40: 0; R_0805_2012Metric_Pad1.20x1.40mm_HandSolder
U5: OPA1656ID; SOIC127P599X175-8N

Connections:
+5V: C45.2, C46.2, U5.8 (V+); also elsewhere on the board
AOUT1: D1.2 (A2), J3.S, R19.1, R23.1
AOUT2: D2.2 (A2), J4.S, R20.1, R31.1
DAC1N: R21.2; also elsewhere on the board
DAC1P: R16.2; also elsewhere on the board
DAC2N: R26.2; also elsewhere on the board
DAC2P: R25.2; also elsewhere on the board
GND: C27.2, C29.2, C30.1, C32.1, C33.1, C34.1, C35.2, C36.2, C45.1, C46.1, D1.1 (A1), D2.1 (A1), J3.T, J4.T, R23.2, R31.2, U5.4 (V_); also elsewhere on the board
HP1: R39.1; also elsewhere on the board
HP2: R40.2; also elsewhere on the board
unnamed: C27.1, R18.2
unnamed: C30.2, R16.1, R17.2, R18.1
unnamed: C32.2, R21.1, R22.2, R24.1
unnamed: C33.2, R25.1, R27.1, R28.2
unnamed: C34.2, R26.1, R29.2, R30.1
unnamed: C35.1, R27.2
unnamed: C39.2, R19.2
unnamed: C40.2, R20.2
unnamed: C29.1, R17.1, U5.3 (+INA)
unnamed: C36.1, R28.1, U5.5 (+INB)
unnamed: C31.1, R22.1, U5.2 (-INA)
unnamed: C37.1, R29.1, U5.6 (-INB)
unnamed: C31.2, C39.1, R24.2, R39.2, U5.1 (OUTA)
unnamed: C37.2, C40.1, R30.2, R40.1, U5.7 (OUTB)

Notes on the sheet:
Output Buffer Difference Amplifier with 2nd Order LPF
OPA1656 Supply Decoupling
Dual SE Stereo Output Connectors Max Voltage Level: 1.8 Vrms

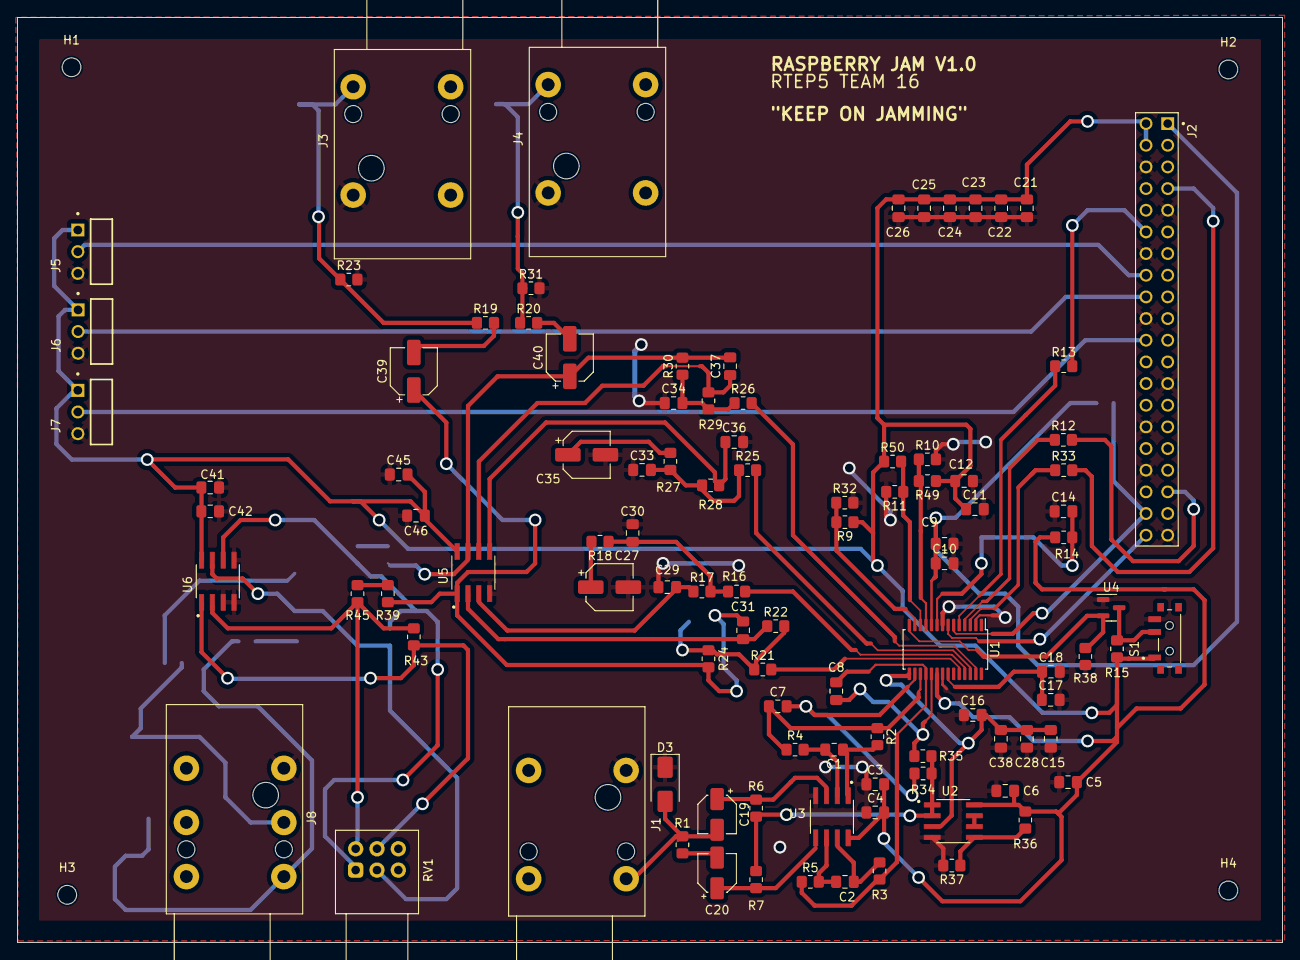
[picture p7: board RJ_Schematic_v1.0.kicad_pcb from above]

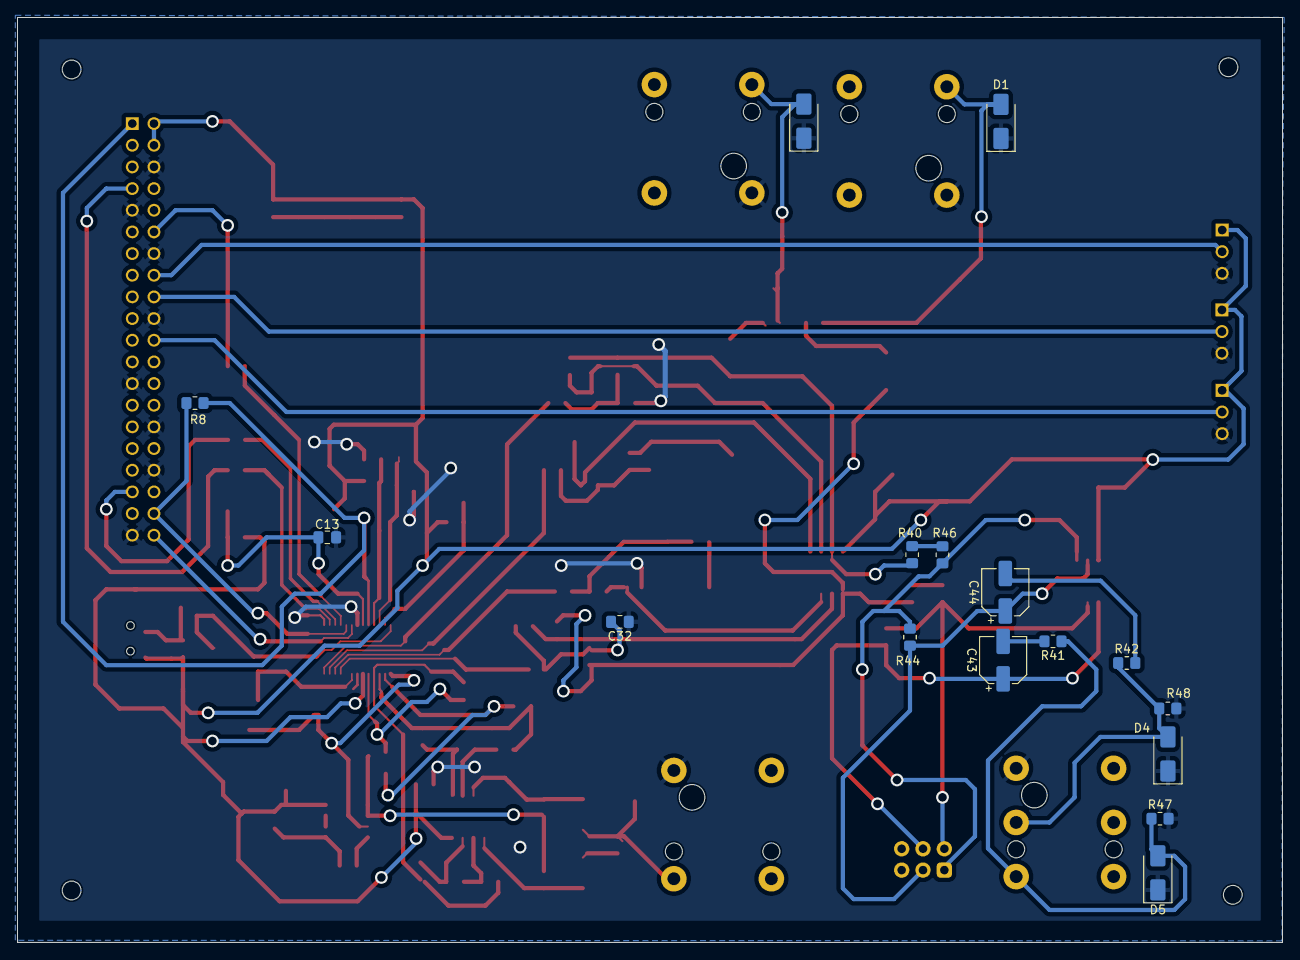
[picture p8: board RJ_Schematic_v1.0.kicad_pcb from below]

Board: 2 copper layers, 148.3 x 108.4 mm, 121 parts (16 on the bottom side), 67 nets.

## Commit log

2024-02-23 hardware files added
    [CS4271.kicad_sch, EXTConnectors.kicad_sch, HPOUT.kicad_sch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]
2024-03-19 added device tree directory for dts files
2024-03-19 remove sample dts file
